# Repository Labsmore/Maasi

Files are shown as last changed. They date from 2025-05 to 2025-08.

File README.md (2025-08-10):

  

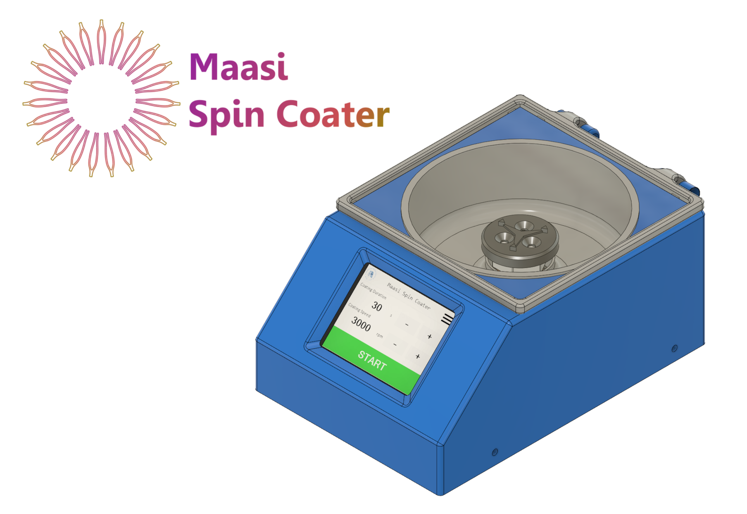
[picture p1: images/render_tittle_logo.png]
poseidon_logo






## maasi: Open source spin coater

A fully 3D printed, easy-to-use and open-source spin coater.

Labsmore fork or original project here: https://github.com/klotzsch-lab/Maasi

We are trying to smooth out some of the rough edges and get it out to more people.
  
You can find some of our notes including pre-compiled firmware here: https://docs.google.com/document/d/1q8YxEo6OFKYewxjzeC29vybrB1PzPGwMxrUwC158PPo/edit?tab=t.0

Want to buy one pre-assembled? Reach out to support@labsmore.com

**Build tutorial**: https://www.youtube.com/watch?v=bhJrJDhlixs

**HardwareX Paper**: In review

## The tl;dr

Here we present Maasi, an affordable Spin Coater that is easy to build and has all functional key features to be used in a wide range of applications up to 8000 RPM. Our design has a price of approximately 85 € and an assembly time of 2 hours. One of the principles that guided the design was to use only 3D printed parts and affordable Commercial Off-The-Shelf (COTS) components. In order to keep a low part count we use an electronic speed controller (ESC) with telemetry, this eliminates the need for a rotor sensor.

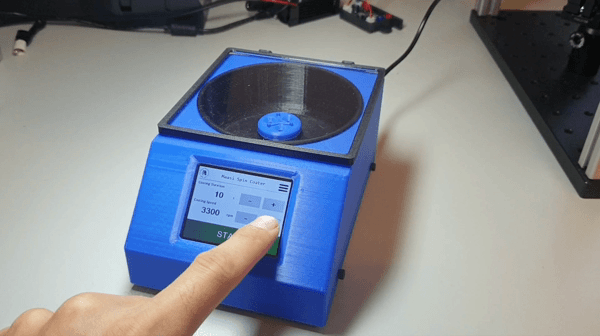
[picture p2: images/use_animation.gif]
using_maasi


## What is included?

* Computer Aided Design (CAD) files of the complete assembly.

* 3D printable .3MF files.

* Nextion Editor project for the Graphical user interface (GUI).

* Arduino firmware source files.

* Bill of materials for sourcing and purchasing materials.

* Detailed assembly instructions of hardware components.

## Getting Started

### 3D printing components and purchasing hardware

The 3D printed components can be fabricated on any desktop fused filament fabrication (FFF) 3D printer. They were designed using [Autodesk Fusion 360](http://autodesk.com/fusion360), a proprietary CAD software that offers free academic licenses.

- Fusion360 interactive view of [maasi spin coaterCAD](https://a360.co/3xFyf5n).

- Bill of materials with prices and vendor links on a [Spreadsheet](https://github.com/klotzsch-lab/Maasi/tree/main/doc/Maasi-BoM.ods).

- Print files (.3MF ) are available in the [/HARDWARE](https://github.com/klotzsch-lab/Maasi/tree/main/HARDWARE/) folder and print details are specified in the HardwareX publication.

### Build Video

Maasi v1: https://www.youtube.com/watch?v=bhJrJDhlixs&t=412s

Further build instructions are detaild in the HardwareX publication. The following is short version of those instrucitions.

### Setting up the ESP32

The ESP32 is the main MCU in Maasi. It coordinates the actions in the coating process and comunicates with the ESC and the Display MCUs.

Use the Arduino IDE to compile and flash the ESP32 (DevKitc V4)

 <strong>IMPORTANT: </strong> Users are experiencing problems (unresponsive touchscreen) with the Arduino ESP32 [v1.0.5](https://github.com/espressif/arduino-esp32/releases) and above. Please use the Board Manager to install v1.0.4 or previous until a fix is released.

**Make sure to install the following libraries**

-  [Nextion library](https://github.com/klotzsch-lab/Maasi/tree/main/SOFTWARE/Arduino/ITEADLIB_Arduino_Nextion). Included in this repository. To install, unzip the zip file to the libraries sub-folder of your sketchbook, if you get stuck here is a [how-to](https://www.arduino.cc/en/guide/libraries).

-  [PID_V1](https://github.com/br3ttb/Arduino-PID-Library)

-  [ElapsedMillis](https://www.arduino.cc/reference/en/libraries/elapsedmillis/)

### Setting up the Nextion Display

The display project was devoloped using Nextion Editor. We provide precompiled binaries if no customization is needed:

Copy into a micro SD card the file: [maasi_v1.tft](https://github.com/klotzsch-lab/Maasi/tree/main/SOFTWARE/Nextion/maasi_v1.tft)

Install the micro SD card in the Nextion display and power it up.

After the flashing process the SD card can be removed.

### Setting up the BLHeli_32 ESC

The ESC firmware is loaded using [BLHeliSuite32](https://github.com/bitdump/BLHeli/releases)

The required version for this project is the v32.7

An arduino UNO or nano is needed as flashing device between the PC and the ESC.

###  Putting together the Hardware
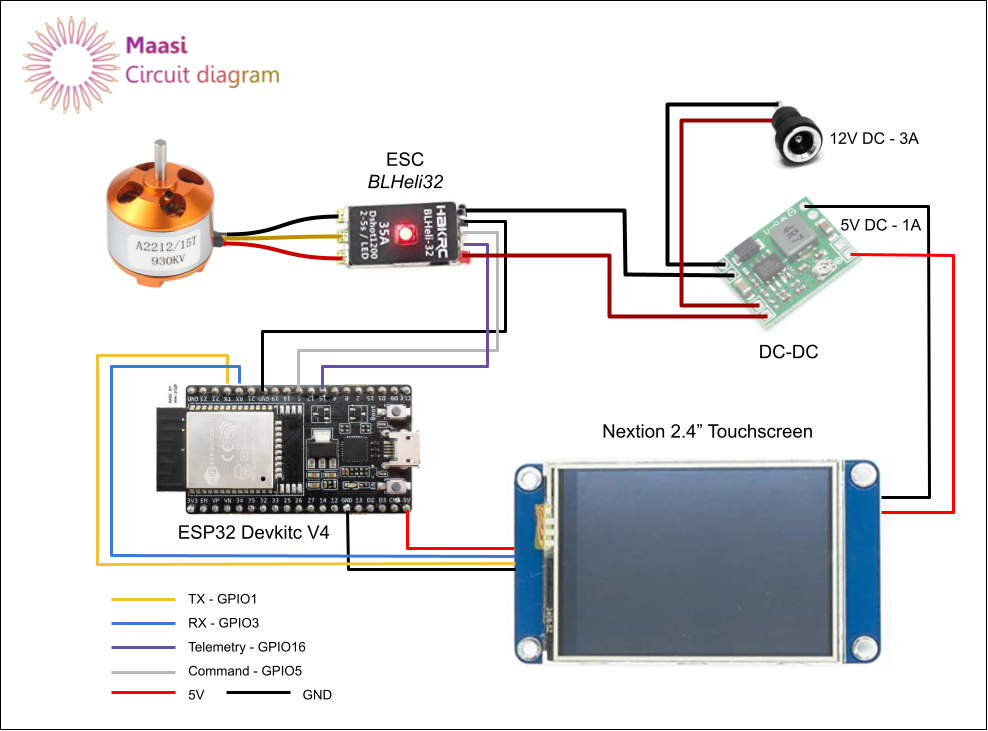
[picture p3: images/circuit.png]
circuit_diagram_maasi


## Safety Considerations

Please review the license before using/developing/distribution maasi.

The maasi spin coater system uses 3D printed PLA plastic and standard off the shelf components which do not pose a health hazard if handled correctly. Improper handling of plastics however can create hazards when working with organic solvents.

The motor can spin at very high RPM and a safety lid was added to reduce the risk of injure in case that the substrate was not properly fixed to the holder.

Before using maasi in a wetlab environment, please ensure that you have thoroughly tested its functionality for your use case in a dry lab. Once the maasi system has been moved into a wetlab, it should not be moved back to a drylab or dry workbench.

If you plan to build on the maasi spin coater, ensure that you communicate any safety concerns that you may have with your design to potential users and collaborators.

## Authors

Maasi was developed by the [Klotzsch Lab](https://www.biologie.hu-berlin.de/en/groupsites/jpexpbp) at HU Berlin by:

-  [Dani Carbonell](https://github.com/dani-carbonell)

-  Willi Weber

-  [Enrico Klotzsch](https://www.biologie.hu-berlin.de/en/groupsites/jpexpbp/members/Enrico_Klotzsch)

#### Prior work and references

The maasi project is based on a number of other open source projects and papers.
A complete references list can be found inside the HardwareX paper.

The idea to use the ESC telemetry was based on the DIY spin coater built by [@BenKrasnow](https://www.youtube.com/watch?v=321tptQ8PrU) (Applied Science in Youtube)

The documentation format was largely inspired by [Pachter Lab](https://pachterlab.github.io/):

[Booeshaghi, A.S., Beltrame, E.d.V., Bannon, D. et al. Principles of open source bioinstrumentation applied to the poseidon syringe pump system. Sci Rep 9, 12385 (2019). https://doi.org/10.1038/s41598-019-48815-9](https://www.nature.com/articles/s41598-019-48815-9)

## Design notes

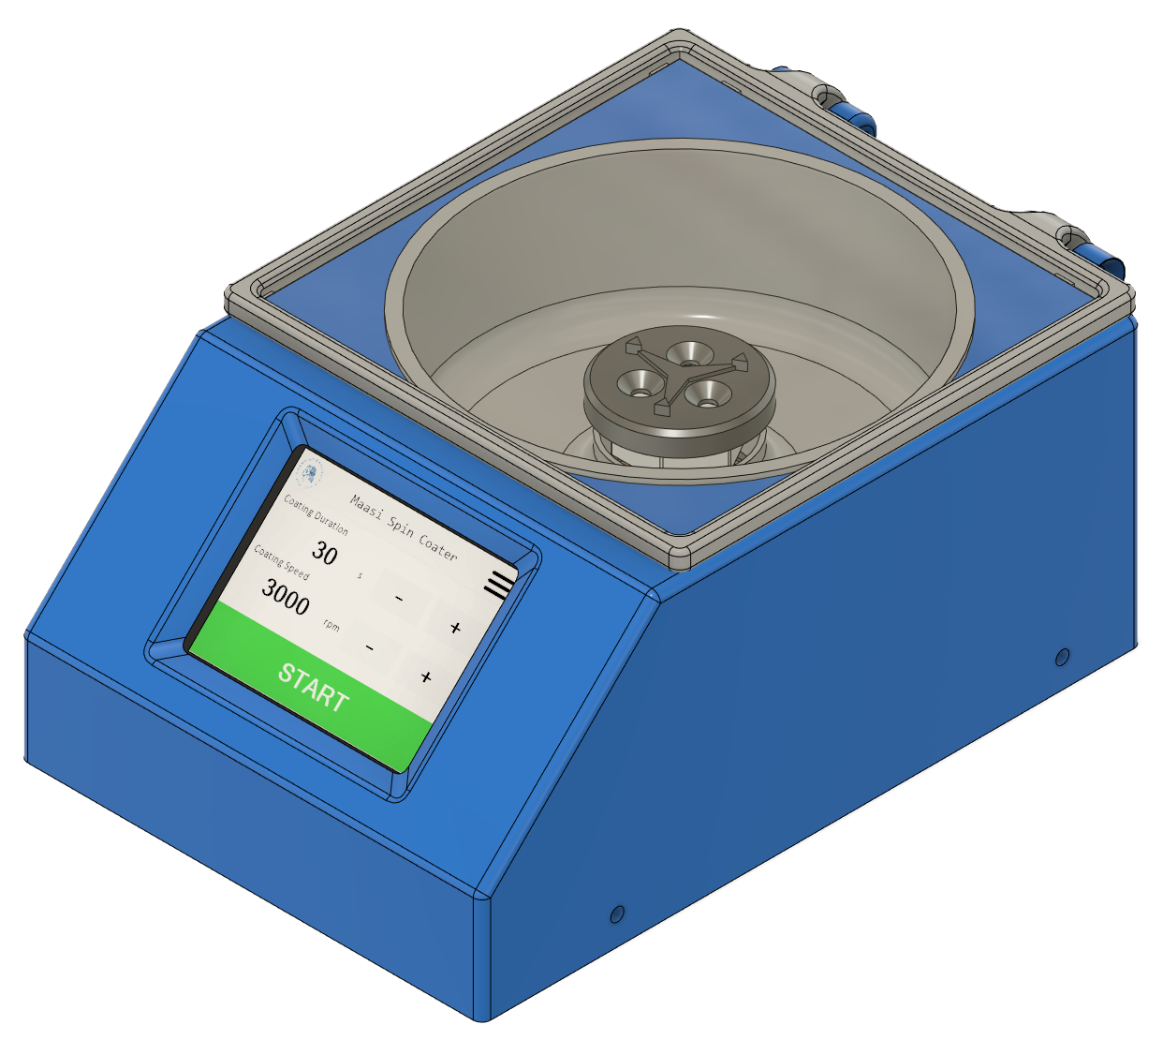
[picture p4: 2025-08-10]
images/render.png

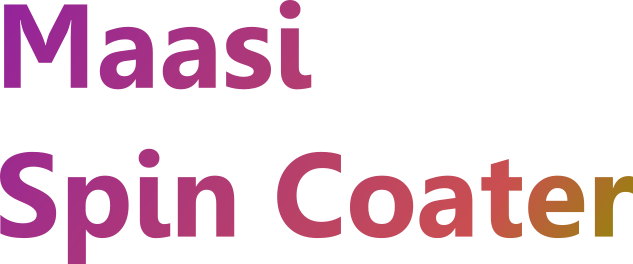
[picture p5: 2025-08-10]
images/maasi_tittle.png

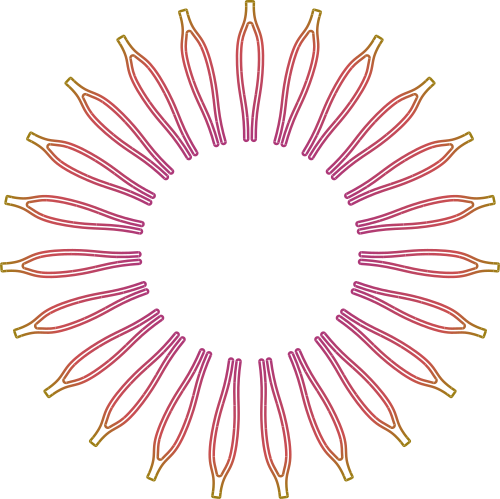
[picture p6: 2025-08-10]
images/maasi_fusion360_500.png

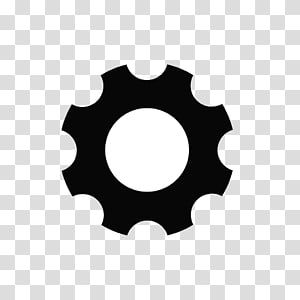
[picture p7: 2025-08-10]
software/nextion/images/5a95ed98d4fc01607e5e6eb79c2b0c93.jpg

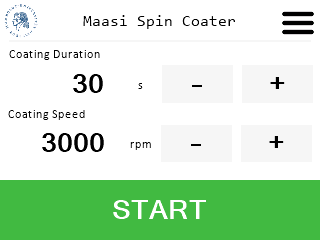
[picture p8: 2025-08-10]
software/nextion/mainscreen_render.png

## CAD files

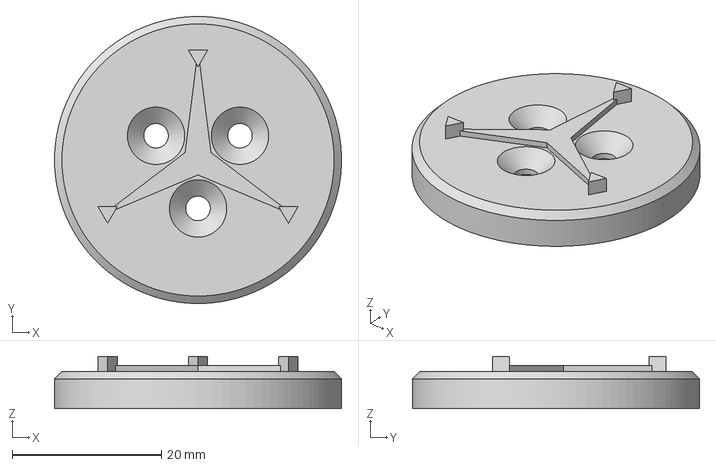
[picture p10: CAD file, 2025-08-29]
hardware/3mf/holder_round_25mm_v1.3mf
38.5 x 38.5 x 7.00 mm

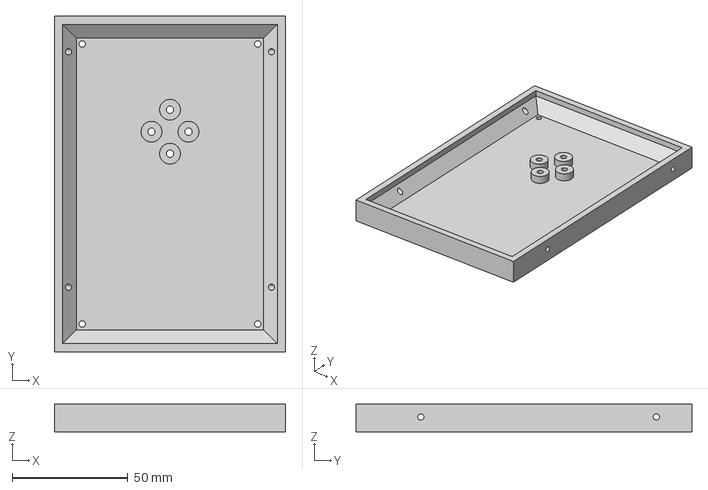
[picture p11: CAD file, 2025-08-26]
hardware/3mf/base_v2.3mf
99.8 x 145.0 x 12.0 mm

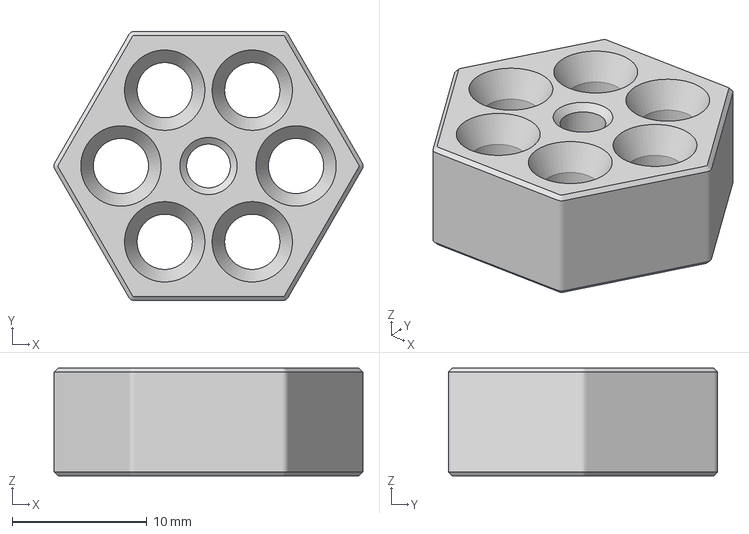
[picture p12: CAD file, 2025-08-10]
hardware/3mf/shaft_adapter_v2.3mf
22.9 x 20.0 x 8.00 mm

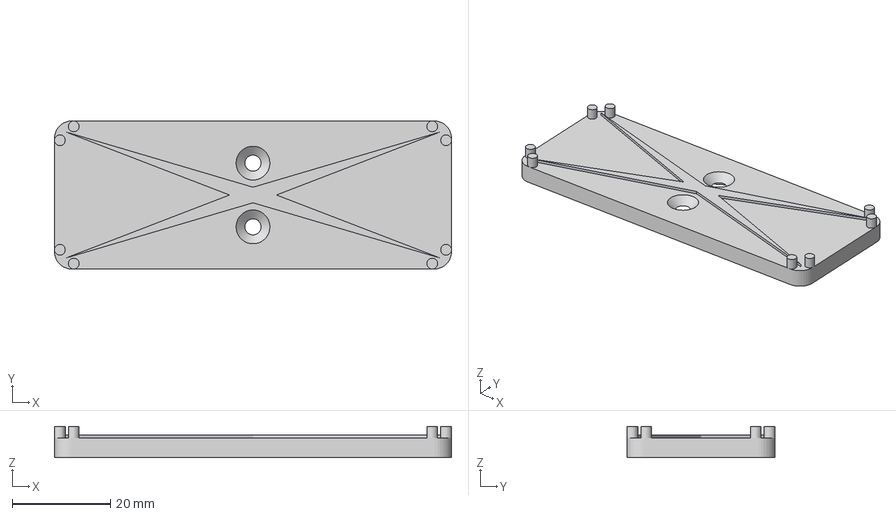
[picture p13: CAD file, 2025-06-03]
hardware/3mf/holder_square_3x1in_v1.3mf
81.0 x 30.2 x 6.40 mm

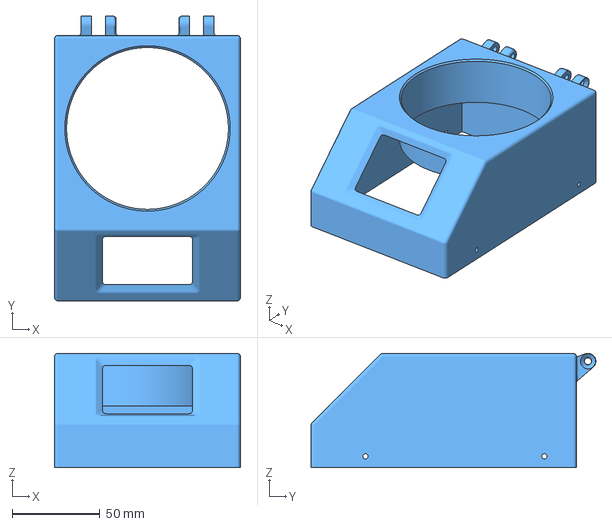
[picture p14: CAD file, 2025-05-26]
hardware/3mf/case_v1.3mf
105.8 x 162.0 x 65.0 mm

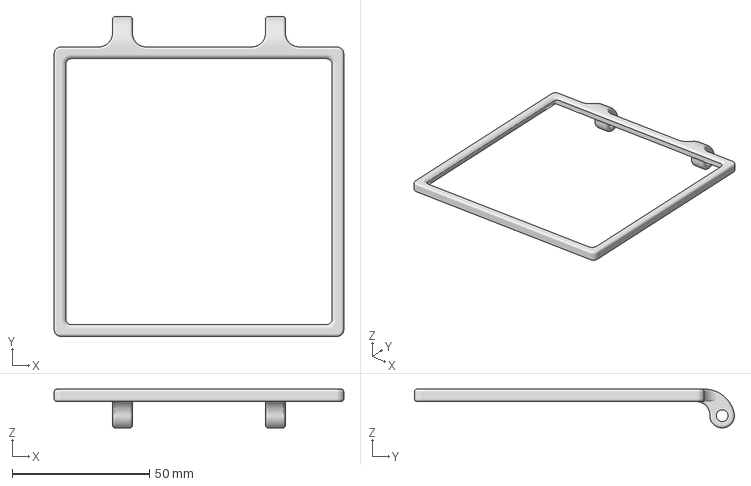
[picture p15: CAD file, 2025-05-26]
hardware/3mf/lid_frame_hinges_v1.3mf
105.6 x 116.7 x 14.2 mm

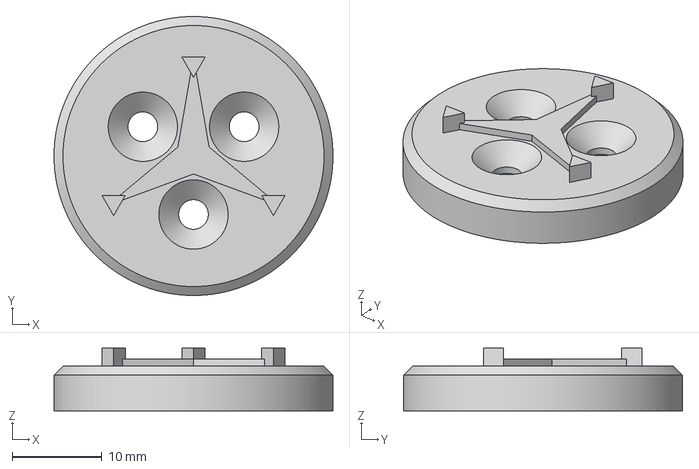
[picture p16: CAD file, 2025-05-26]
hardware/3mf/holder_round_18mm_v1.3mf
31.0 x 31.0 x 7.00 mm

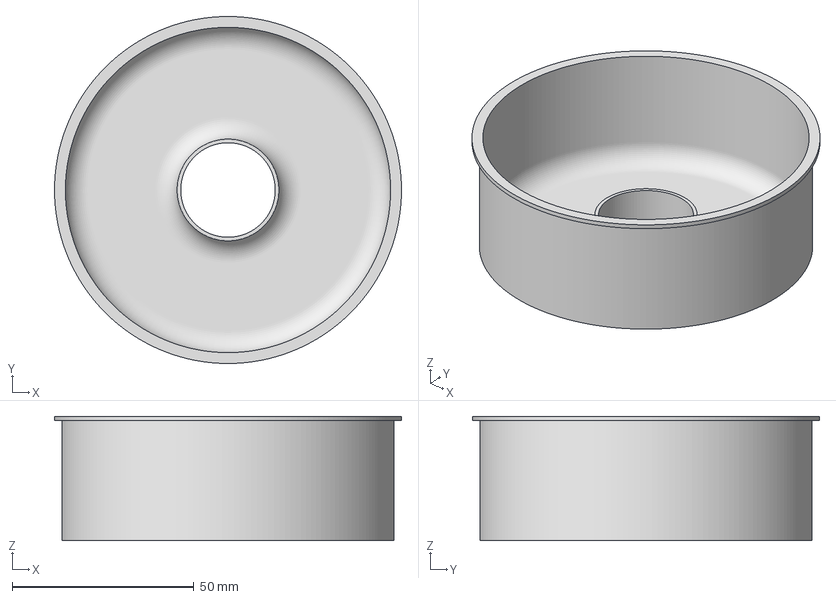
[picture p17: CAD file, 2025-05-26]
hardware/3mf/vase_v1.3mf
95.5 x 95.5 x 34.2 mm

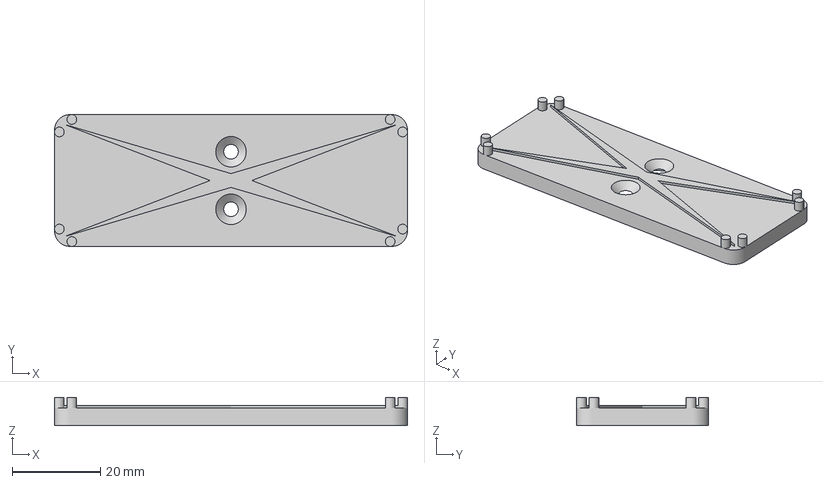
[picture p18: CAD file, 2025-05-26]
hardware/3mf/holder_square_75x25mm_v1.3mf
79.8 x 29.8 x 6.40 mm

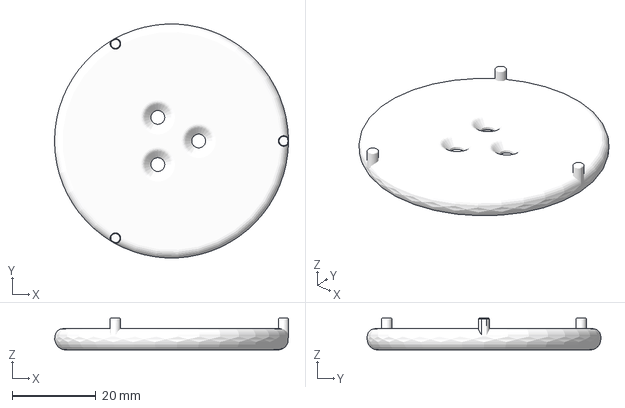
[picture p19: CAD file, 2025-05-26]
hardware/3mf/holder_round_2in_v1.3mf
55.9 x 55.8 x 7.62 mm

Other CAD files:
hardware/3mf/archive/base_v1.3mf
hardware/3mf/archive/shaft_adapter_v1.3mf
hardware/3mf/shaft_adapter_v1.3mf
hardware/3mf/base_v1.3mf
hardware/fusion360/Maasi_Spin_Coater RC1.f3z
hardware/fusion360/base_v2.f3z
hardware/fusion360/holder_round_25mm_v1.f3d
hardware/fusion360/shaft_adapter_v2.f3d

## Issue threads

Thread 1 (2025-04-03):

Investigate motor stalls

JohnDMcMaster, 2025-04-03:
Occasionally stalls out. Known issue. Control loop issue or something else? dshot300 => maybe compatible with other controller as well, although need to look at telemetry (upgrade to the FOSS firmware instead?)

JohnDMcMaster, 2025-08-26:
This was fixed by build procedure changes. Root cause was plastic getting crushed which sometimes could encroach on motor bearing. Fixes:
-Add washers between motor and plastic case
-Switch from 15% infill to 70% (min) to 100% (recommended) infill

Closed 2025-08-26.

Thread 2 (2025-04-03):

Publish more concrete build instructions

JohnDMcMaster, 2025-04-03:
Building another 2x units. Rev them when I do those

Include:
- Reference firmware files (screen + esp32)
- Reference wire gauge / type / length
- Our custom wafer adapter
- Updated info on ESC test results

JohnDMcMaster, 2025-08-26:
https://docs.google.com/document/d/12Gl7_J1RtsuV03IdRyFFwjkz43eO1kORZ48vfHqdVy0/edit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

Its not linked from the README I think but this is my version

Closed 2025-08-26.

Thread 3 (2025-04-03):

Clean up ESP32 wiring?

JohnDMcMaster, 2025-04-03:
Dupont style connectors aren't the most reliable. Maybe use breakout board?

JohnDMcMaster, 2025-08-26:
I went through a few iterations on this. I settled on using the Francy2 5V regulator instead of adding my own 5V regulator. Then I use a crimp connector to splice the 5V into the display 5V line. There is no longer any direct soldering to the display

Other: I attempted using vampire taps to make this quicker. It was shown to have reliability issues and was reverted on 2/3 of the units (one made it out, but so far its reliable)

Closed 2025-08-26.

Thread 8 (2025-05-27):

DFM pass on rotor shaft adapter

JohnDMcMaster, 2025-05-27:
Ideas:
- Chamfer inserts allow relief when material flows
- Make a retention bracket to reinforce sides when pressing. Can do hotter etc
- Review keying scheme. Do we need both hex lock as well as 6 bolts? We could make it thicker if we aborted hex scheme. ie ideally either 6 bolts OR 1 bolt in the center + hex, but both seems redundant

JohnDMcMaster, 2025-08-26:
Inserts were chamfered (shaft_adapter_v2.3mf). Retention bracket seems unnecessary now

Ignore the keying scheme for now unless we have a good reason to change it

Closed 2025-08-26.

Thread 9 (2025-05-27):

Vacuum chuck ideas

JohnDMcMaster, 2025-05-27:
We are exploring a number of rev ideas

Some of the top ideas:
- Get a hollow shaft motor (drones use them for weight reduction). Put the entire case under vacuum to suck through it
- Rotary seal between chuck and case which is under vacuum
- Venturi on chuck itself to hold vacuum

General concerns over how well a 3d printed vacuum chuck works at all. Maybe verify / research existing work here first

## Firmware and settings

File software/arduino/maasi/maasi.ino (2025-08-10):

#include <HardwareSerial.h>
#include "freertos/FreeRTOS.h"
#include "freertos/task.h"
#include "freertos/event_groups.h"
#include "Arduino.h"
#include "esp32-hal.h"
#include "nextion_hmi.h"
#include <elapsedMillis.h>
#include <PID_v1.h>


#define DEFAULT_DISPENSE_SPEED 600       // RPM
#define DEFAULT_COAT_SPEED 3000          
#define MIN_COAT_SPEED 300
#define MAX_COAT_SPEED 8000
#define INCREMETS_COAT_SPEED 100



#define DEFAULT_COAT_TIME 30000 // In ms
#define MIN_COAT_TIME 1000
#define MAX_COAT_TIME 80000
#define INCREMETS_COAT_TIME 1000
#define DEFAULT_RAMPUP_TIME 3000
#define MIN_RAMPUP_TIME 1000
#define MAX_RAMPUP_TIME 6000
#define DEFAULT_RAMPDOWN_TIME 1500
#define MIN_RAMPDOWN_TIME 500
#define MAX_RAMPDOWN_TIME 5000

#define MOTOR_POLE_PAIRS 7

#define GREY 54970
#define GREEN 17864


//---------------------------------------
//  Coating params
//---------------------------------------

uint16_t disp_speed, coat_speed;

int32_t rampup_time, rampdown_time, coat_time;

enum state {
  STATE_IDLE,
  STATE_DISPENSING,
  STATE_RAMPUP,
  STATE_RAMPDOWN,
  STATE_COATING
};

state current_state, previous_state = STATE_IDLE;

//----------------------------------------------------------------------------
// Espressif Infrared Remote(rmt) library is used to create DSHOT messages in a fast manner
//-----------------------------------------------------------------------------

TaskHandle_t Task1;

rmt_data_t dshotPacket[16];
rmt_obj_t* rmt_send = NULL;

hw_timer_t * timer = NULL;

HardwareSerial TelSerial(1);

// ESC Telemetry variables
uint8_t receivedBytes = 0;
volatile bool requestTelemetry = false;
int16_t ESC_telemetry[5]; // Temperature, Voltage, Current, used mAh, eRpM
//uint32_t telemetry_fails = 0;
//uint32_t telemetry_succ = 0;


uint32_t currentTime;
uint8_t temperature = 0;
uint8_t temperatureMax = 0;
float voltage = 0;
float voltageMin = 99;
uint32_t current = 0;
uint32_t currentMax = 0;
uint32_t erpm = 0;
uint32_t erpmMax = 0;
uint32_t rpm = 0;
uint32_t rpmMAX = 0;
uint32_t kv = 0;
uint32_t kvMax = 0;

//---------------------------------------
//   PID parameters
//---------------------------------------
double motor_setRPM, motor_actualRPM, pid_output = 0;
double pid_out_min = 48;
double pid_out_max = 2047;
double Kp = 0.015, Ki = 0.8 , Kd = 0.0; // Before 1,3,0
const int sample_time = 1; //ms


PID motorPID(&motor_actualRPM, &pid_output, &motor_setRPM, Kp, Ki, Kd, DIRECT);


//---------------------------------------
//   ESC Control Parameters
//---------------------------------------

uint16_t dshotUserInputValue = 0;
uint16_t dshotmin = 48;
uint16_t dshotmax = 2047;

void IRAM_ATTR getTelemetry() {
  requestTelemetry = true;
}

void startTelemetryTimer() {
  timer = timerBegin(0, 80, true); // timer_id = 0; divider=80; countUp = true;
  timerAttachInterrupt(timer, &getTelemetry, true); // edge = true
  timerAlarmWrite(timer, 1000, true);  //1000 = 1 ms
  timerAlarmEnable(timer);
}

// Second core used to send DSHOT packets
void secondCoreTask( void * pvParameters ) {
  while (1) {

    if (requestTelemetry) {
      dshotOutput(dshotUserInputValue, requestTelemetry);
      requestTelemetry = false;
      receivedBytes = 0;
    }

    delay(1);
  }
}

//---------------------------------------
//   Nextion Callbacks
//---------------------------------------


 // START
 
void b1PushCallback(void *ptr)
{
    startDispense();
}

 // STOP
 
void p2b0PushCallback(void *ptr)
{
  if (current_state != STATE_RAMPDOWN){
      startRampdown();    
    }
}

 // COAT
void p2b1PushCallback(void *ptr)
{
  if (current_state == STATE_DISPENSING){
      startRampup();    
    }
}

 // SET BUTTONS
 
void b2PushCallback(void *ptr)
{
   if (coat_time > MIN_COAT_TIME){
    coat_time -= INCREMETS_COAT_TIME;
    }
   n0.setValue(coat_time/1000);

}

void b3PushCallback(void *ptr)
{
    if (coat_time < MAX_COAT_TIME){
    coat_time += INCREMETS_COAT_TIME;
    }
    n0.setValue(coat_time/1000);
}

void b4PushCallback(void *ptr)
{
  if (coat_speed > MIN_COAT_SPEED){
    coat_speed -= INCREMETS_COAT_SPEED;
    }
    n1.setValue(coat_speed);
}

void b5PushCallback(void *ptr)
{
    if (coat_speed < MAX_COAT_SPEED){
    coat_speed += INCREMETS_COAT_SPEED;
    }
    n1.setValue(coat_speed); 
}

void b6PushCallback(void *ptr)
{
    p1.show();
    p1n0.setValue(disp_speed);
    p1n1.setValue(rampup_time/1000);     
    p1n2.setValue(rampdown_time);  
}

void p1b0PushCallback(void *ptr)
{
   if (disp_speed > MIN_COAT_SPEED){
    disp_speed -= INCREMETS_COAT_SPEED/2;
    }
   p1n0.setValue(disp_speed);

}

void p1b1PushCallback(void *ptr)
{
    if (disp_speed < MAX_COAT_SPEED){
    disp_speed += INCREMETS_COAT_SPEED/2;
    }
    p1n0.setValue(disp_speed);
}

void p1b2PushCallback(void *ptr)
{
  if (rampup_time > MIN_RAMPUP_TIME){
    rampup_time -= INCREMETS_COAT_TIME;
    }
    p1n1.setValue(rampup_time/1000);
}

void p1b3PushCallback(void *ptr)
{
    if (rampup_time < MAX_RAMPUP_TIME){
    rampup_time += INCREMETS_COAT_TIME;
    }
    p1n1.setValue(rampup_time/1000); 
}

void p1b4PushCallback(void *ptr)
{
  if (rampdown_time > MIN_RAMPDOWN_TIME){
    rampdown_time -= INCREMETS_COAT_TIME/2;
    }
    p1n2.setValue(rampdown_time);
}

void p1b5PushCallback(void *ptr)
{
  if (rampdown_time < MAX_RAMPDOWN_TIME){
    rampdown_time += INCREMETS_COAT_TIME/2;
    }
    p1n2.setValue(rampdown_time);
}

void p1b6PushCallback(void *ptr)
{

}

void p1b7PushCallback(void *ptr)
{

}
//---------------------------------------
//   Timers
//---------------------------------------
elapsedMillis time_since_display_update = 0;

elapsedMillis time_ramping = 0;
elapsedMillis time_coating = 0;

//elapsedMicros time_since_telemetry = 0;

const int display_update_time = 100;



//---------------------------------------
//   SETUP
//---------------------------------------

void setup() {

  Serial.begin(115200);
  TelSerial.begin(115200, SERIAL_8N1, 16, 17);

  // Init DSHOT hardware
  if ((rmt_send = rmtInit(5, true, RMT_MEM_64)) == NULL) {
    Serial.println("init sender failed\n");
  }

  float realTick = rmtSetTick(rmt_send, 12.5); // 12.5ns sample rate
  //Serial.printf("rmt_send tick set to: %fns\n", realTick);

  // Output disarm signal while esc initialises and do some display stuff.
  uint8_t xbeep = random(15, 100);
  uint8_t ybeep = random(15, 50);
  uint8_t ibeep = 0;
  while (millis() < 3500) {
    dshotOutput(0, false);
    delay(1);

    /// display.clear();
    ibeep++;
    if (ibeep == 100) {
      ibeep = 0;
      xbeep = random(15, 50);
      ybeep = random(15, 50);
    }
  }


  // Empty Rx Serial of garbage telemtry
  while (TelSerial.available()){
    TelSerial.read();
    }
  requestTelemetry = true;
  startTelemetryTimer(); // Timer used to request tlm continually in case ESC rcv bad packet
  xTaskCreatePinnedToCore(secondCoreTask, "Task1", 10000, NULL, 1, &Task1, 0);


  //PID
  coat_speed = DEFAULT_COAT_SPEED;
  disp_speed = DEFAULT_DISPENSE_SPEED;
  coat_time = DEFAULT_COAT_TIME;
  rampup_time = DEFAULT_RAMPUP_TIME;
  rampdown_time = DEFAULT_RAMPDOWN_TIME;
  
  motorPID.SetOutputLimits(pid_out_min, pid_out_max);
  motorPID.SetSampleTime(sample_time);
  
  // Touchscreen init
  nexInit();
  b1.attachPush(b1PushCallback);
  b2.attachPush(b2PushCallback);
  b3.attachPush(b3PushCallback);
  b4.attachPush(b4PushCallback);
  b5.attachPush(b5PushCallback);
  b6.attachPush(b6PushCallback); 
  p1b0.attachPush(p1b0PushCallback);
  p1b1.attachPush(p1b1PushCallback);
  p1b2.attachPush(p1b2PushCallback);
  p1b3.attachPush(p1b3PushCallback);
  p1b4.attachPush(p1b4PushCallback);
  p1b5.attachPush(p1b5PushCallback);
  p1b6.attachPush(p1b6PushCallback);
  p1b7.attachPush(p1b7PushCallback); 
  p2b0.attachPush(p2b0PushCallback);
  p2b1.attachPush(p2b1PushCallback);

  initDisplay();


}


//---------------------------------------
//   LOOP
//---------------------------------------
void loop() {

  nexLoop(nex_listen_list); //Check callback list
  updateDisplay();
  if (!requestTelemetry) {
    motorPID.Compute();
    receiveTelemtry();
  }
  updateMotor();
}

void stopCoating(){
  p0.show();
  current_state = STATE_IDLE;
  }
  
void startDispense(){
  p2.show();
  p2b1.Set_background_color_bco(GREEN); //Set button Green
  t4.setText("Dispense fluid");
  current_state = STATE_DISPENSING;
  
  motor_setRPM = disp_speed;
  motorPID.SetMode(AUTOMATIC); 
  }
  
void startRampup(){
  p2b1.Set_background_color_bco(GREY); //Set button Grey
  t4.setText("Ramping up");
  current_state = STATE_RAMPUP;
  
  motorPID.SetMode(AUTOMATIC);
  time_ramping = 0;
  }
  
void startRampdown(){
  t4.setText("Ramping down");
  current_state = STATE_RAMPDOWN;
  
  motorPID.SetMode(AUTOMATIC);
  time_ramping = 0; 
  }
  
void startCoating(){
  //p2.show();
  //p2b1.Set_background_color_bco(GREY); //Set button Grey
  t4.setText("Coating");
  current_state = STATE_COATING;
 
  motor_setRPM = coat_speed; 
  motorPID.SetMode(AUTOMATIC); 
  time_coating = 0;
  }

void initDisplay(){
    n0.setValue(coat_time/1000);
    n1.setValue(coat_speed);
    p1n0.setValue(disp_speed);
    p1n1.setValue(rampup_time/1000);
    p1n2.setValue(rampdown_time);
  }

void updateDisplay() {

  if (time_since_display_update >= display_update_time) {
    time_since_display_update = 0;

    switch (current_state){
      case STATE_IDLE:  
        break;
        
      case STATE_DISPENSING:
        p2n0.setValue(coat_time/1000);
        p2n1.setValue(motor_actualRPM);
        p2j0.setValue(0);
        break;
      case STATE_RAMPUP:      
        p2n0.setValue((rampup_time - time_ramping)/1000);
        p2n1.setValue(motor_actualRPM);
        //p2j0.setValue(100-(rampup_time - time_ramping)*100/rampup_time);
        break;      
      case STATE_RAMPDOWN:      
        p2n0.setValue((rampdown_time - time_ramping)/1000);
        p2n1.setValue(motor_actualRPM);
        p2j0.setValue(0);
        break;     
      case STATE_COATING:      
        p2n0.setValue((coat_time - time_coating)/1000);
        p2n1.setValue(motor_actualRPM);
        p2j0.setValue((coat_time - time_coating)*100/coat_time); // % Progress bar
        //p2n0.setValue(abs(coat_speed - motor_actualRPM)); //Debuging RPM error 
        break;
    } 
  }
}


void updateMotor() {

    motor_actualRPM = rpm;

    
    switch (current_state){
      case STATE_IDLE:
       motorPID.SetMode(MANUAL); 
       dshotUserInputValue = 0;
       pid_output = 0;    
       break;
        
      case STATE_DISPENSING:
        dshotUserInputValue = pid_output;
        break;
        
      case STATE_RAMPUP:
        if (time_ramping < rampup_time){
          motor_setRPM = map(time_ramping, 0, rampup_time, disp_speed, coat_speed);
          dshotUserInputValue = pid_output;     
          }
        else{
          startCoating();
          }     
        break;
        
      case STATE_COATING:
        if (time_coating < coat_time){
          dshotUserInputValue = pid_output;    
          }
        else{
          startRampdown();
          }     
        break;

      case STATE_RAMPDOWN:
        int rampdown_speed = motor_actualRPM;
        if (time_ramping < rampdown_time){
          motor_setRPM = map(time_ramping, 0, rampdown_time, rampdown_speed, 0 );
          dshotUserInputValue = pid_output;     
          }
        else{
          stopCoating();
          }     
        break;

    }

}



void receiveTelemtry() {


  static uint8_t SerialBuf[10];

  if (TelSerial.available()) {
    SerialBuf[receivedBytes] = TelSerial.read();
    receivedBytes++;
  }

  if (receivedBytes > 9) { // transmission complete

    uint8_t crc8 = get_crc8(SerialBuf, 9); // get the 8 bit CRC

    if (crc8 != SerialBuf[9]) {
      //                Serial.println("CRC transmission failure");

      // Empty Rx Serial of garbage telemtry
      while (TelSerial.available())
        TelSerial.read();

      requestTelemetry = true;
      //telemetry_fails++;
      return; // transmission failure
    }

    // compute the received values
    ESC_telemetry[0] = SerialBuf[0]; // temperature
    ESC_telemetry[1] = (SerialBuf[1] << 8) | SerialBuf[2]; // voltage
    ESC_telemetry[2] = (SerialBuf[3] << 8) | SerialBuf[4]; // Current
    ESC_telemetry[3] = (SerialBuf[5] << 8) | SerialBuf[6]; // used mA/h
    ESC_telemetry[4] = (SerialBuf[7] << 8) | SerialBuf[8]; // eRpM *100

    //telemetry_succ++;
    requestTelemetry = true;
    // Update values and smooth

    /*
    temperature = 0.9 * temperature + 0.1 * ESC_telemetry[0];
    if (temperature > temperatureMax) {
      temperatureMax = temperature;
    }

    voltage = 0.9 * voltage + 0.1 * (ESC_telemetry[1] / 100.0);
    if (voltage < voltageMin) {
      voltageMin = voltage;
    }

    current = 0.9 * current + 0.1 * (ESC_telemetry[2] * 100);
    if (current > currentMax) {
      currentMax = current;
    }
    */
    //erpm = 0.7 * erpm + 0.3 * (ESC_telemetry[4] * 100);
    erpm = ESC_telemetry[4] * 100;
    if (erpm > erpmMax) {
      erpmMax = erpm;
    }

    rpm = erpm / (MOTOR_POLE_PAIRS);
    if (rpm > rpmMAX) {
      rpmMAX = rpm;
    }

  }

  return;
}


void dshotOutput(uint16_t value, bool telemetry) {

  uint16_t packet;

  // telemetry bit
  if (telemetry) {
    packet = (value << 1) | 1;
  } else {
    packet = (value << 1) | 0;
  }

  // https://github.com/betaflight/betaflight/blob/09b52975fbd8f6fcccb22228745d1548b8c3daab/src/main/drivers/pwm_output.c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
  int csum = 0;
  int csum_data = packet;
  for (int i = 0; i < 3; i++) {
    csum ^=  csum_data;
    csum_data >>= 4;
  }
  csum &= 0xf;
  packet = (packet << 4) | csum;

  // durations are for dshot600
  // https://blck.mn/2016/11/dshot-the-new-kid-on-the-block/
  // Bit length (total timing period) is 1.67 microseconds (T0H + T0L or T1H + T1L).
  // For a bit to be 1, the pulse width is 1250 nanoseconds (T1H – time the pulse is high for a bit value of ONE)
  // For a bit to be 0, the pulse width is 625 nanoseconds (T0H – time the pulse is high for a bit value of ZERO)
  for (int i = 0; i < 16; i++) {
    if (packet & 0x8000) {
      dshotPacket[i].level0 = 1;
      dshotPacket[i].duration0 = 100;
      dshotPacket[i].level1 = 0;
      dshotPacket[i].duration1 = 34;
    } else {
      dshotPacket[i].level0 = 1;
      dshotPacket[i].duration0 = 50;
      dshotPacket[i].level1 = 0;
      dshotPacket[i].duration1 = 84;
    }
    packet <<= 1;
  }

  rmtWrite(rmt_send, dshotPacket, 16);

  return;
}

uint8_t update_crc8(uint8_t crc, uint8_t crc_seed) {
  uint8_t crc_u, i;
  crc_u = crc;
  crc_u ^= crc_seed;
  for ( i = 0; i < 8; i++) crc_u = ( crc_u & 0x80 ) ? 0x7 ^ ( crc_u << 1 ) : ( crc_u << 1 );
  return (crc_u);
}

uint8_t get_crc8(uint8_t *Buf, uint8_t BufLen) {
  uint8_t crc = 0, i;
  for ( i = 0; i < BufLen; i++) crc = update_crc8(Buf[i], crc);
  return (crc);
}

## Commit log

2025-05-26 2" wafer holder contributed from Randy Moore
    [fossf_2in_wafer_holder.stl, fossf_fossf_2in_wafer_holder.3mf]
2025-05-26 3mf: noramlize file names
    [base.3mf, case.3mf, fossf_2in_wafer_holder.stl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]
2025-06-03 3x1 slide holder
    [holder_square_3x1in.3mf, holder_square_75x25mm.3mf]
2025-08-10 lowercase file names
    [Maasi_Spin_Coater RC1.f3z, base.3mf, case.3mf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]
2025-08-10 3mf: add verion names
    [base_v1.3mf, case_v1.3mf, holder_round_18mm_v1.3mf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]
2025-08-10 hardware: versioned 3mf file names
    [holder_round_2in_v1.3mf, shaft_adapter_v2.3mf]
2025-08-26 base v2
    [base_v1.3mf, base_v2.3mf, base_v2.f3z]
2025-08-26 move old shaft adapter out of the way
    [shaft_adapter_v1.3mf]
2025-08-29 add old round holder files
    [holder_round_25mm.f3d, holder_round_25mm_v1.3mf]
2025-08-29 fix name
    [holder_round_25mm_v1.f3d]
